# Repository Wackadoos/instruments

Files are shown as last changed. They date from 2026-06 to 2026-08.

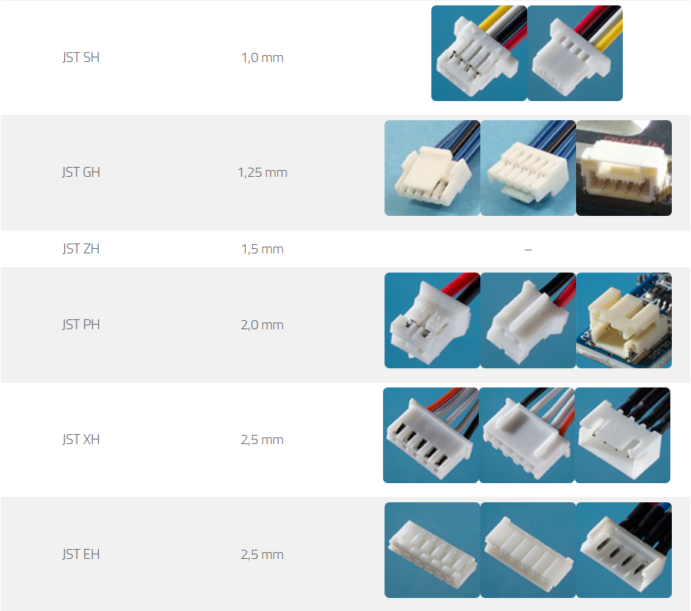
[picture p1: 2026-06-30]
circuitry/resources/JST Connector Identification.png

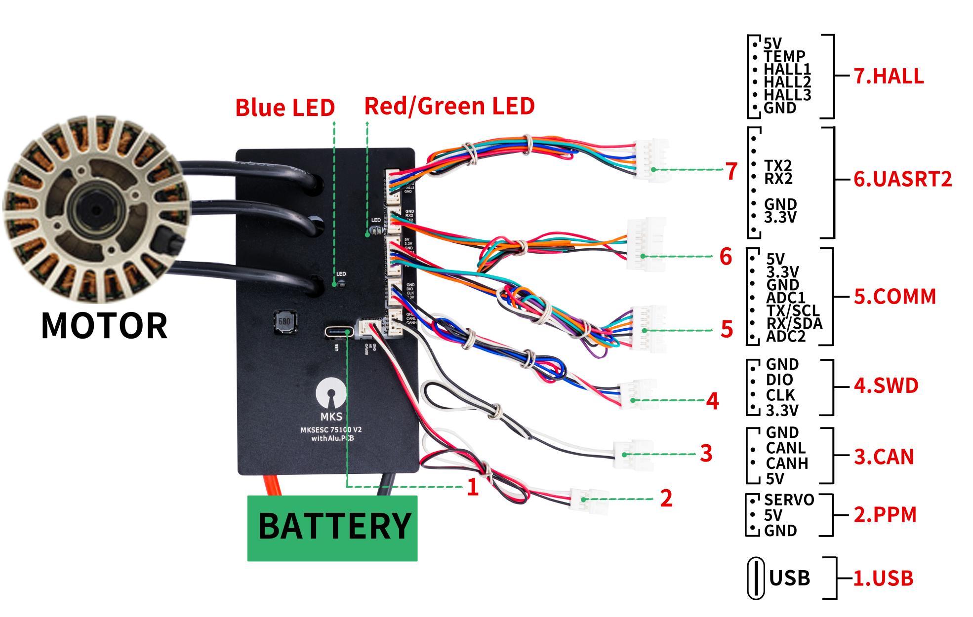
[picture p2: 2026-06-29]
circuitry/resources/Flipsky_75100.jpg

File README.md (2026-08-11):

# instruments

Software to run in-vehicle instruments

## FLIPSKY 75100 Pro v1 Settings

Unless specified below, leave settings as default!

### Firmware

Stock ESC comes with VESC v5.02. Download and flash the latest (should be v7.0 or higher). Notes:

- The hardware is classified incorrectly as 75_300_R2, this is okay as it is compatible.
- All settings will be reset with the update
- Phase Filters will be enabled by default, but are **NOT COMPATIBLE** with this hardware. If running a brushless motor (not the greenpower standard DC motor) this needs to be turned off or the hardware will be damaged!

### Motor Settings

#### General

General:

- Motor Type: DC

Current:

- Motor Current Max: 45.00 A
- Motor Current Max Brake: -45.00 A
- Absolute Maximum Current: 420.00 A
- Battery Current Max: 36.00 A
- Battery Current Max Regen: -36.00 A
- DRV8301 OC Mode: Disabled

Voltage:

- Battery Voltage Cutoff Start: 20.0 V
- Battery Voltage Cutoff End: 16.0 V
- Battery Voltage Regen Cutoff Start: 28.0 V
- Battery Voltage Regen Cutoff End: 30.0 V

Temperature:

- Motor Temperature Sensor Type: Disabled

BMS:

- BMS type: None

Advanced:

- Minimum Input Voltage: 11.0 V
- Maximum Input Voltage: 36.0 V
- Fault Stop Time: 3000 ms

#### DC

- Current Controller Gain: 0.00460
- Current Controller Ramp Step Max: 0.0400
- Current Backoff Gain: 0.5000
- Switching Frequency: 25.00 kHz

#### Additional Info

Setup:

- Battery Type: BATTERY_TYPE_LEAD_ACID
- Battery Cells Series: 12
- Battery Capacity: 36 AH
- Motor No-load Current: 1.0 A

Motor General:

- Motor Brand: Greenpower Motor
- Motor Model: 105ZDY08

### App Settings

#### General

General:

- APP to Use: ADC and UART
- Timeout Brake Current: 0.0 A
- CAN Mode: Unused
- Kill Switch Mode: PPM High

#### ADC

General:

- Control Type: Current No Reverse Brake Center
- Use Filter: True
- Safe Start: Disabled
- Update Rate: 500 Hz
- Positive Ramping Time: 0.3 s
- Negative Ramping Time: 0.1 s
- Multiple VESCs Over CAN: FALSE

Mapping:

- Input Deadband: 15%
- ADC1 Start Voltage: 0.1 V
- ADC1 End Voltage: 3.2 V
- ADC1 Centre Voltage: 1.0 V
- Invert ADC1 Voltage: False
- ADC1 Abs Min Voltage: 0.0 V
- ADC1 Abs Max Voltage: 3.5 V
- ADC2 Start Voltage: 0.1 V
- ADC2 End Voltage: 3.2 V
- Invert ADC2 Voltage: False

#### UART

Baudrate: 250000 bps

#### IMU

IMU Type: IMU_TYPE_OFF

### SWD

To program an NRF51822 for Bluetooth connectivity to the ESC, connect to the swd pins (DIO -> SDO & CLK -> SCLK) and press connect in VESC. Then, select the firmware with RX: 11 TX: 9 and flash it. After, you can connect the pins P0.11 -> TX2 and P0.9 -> RX2 to allow the bluetooth module to talk to the ESC on it's secondary serial port (leaving the primary for app usage ie connecting with arduino etc.)

## SD Cards

### Detecting Fake Cards

https://github.com/AltraMayor/f3

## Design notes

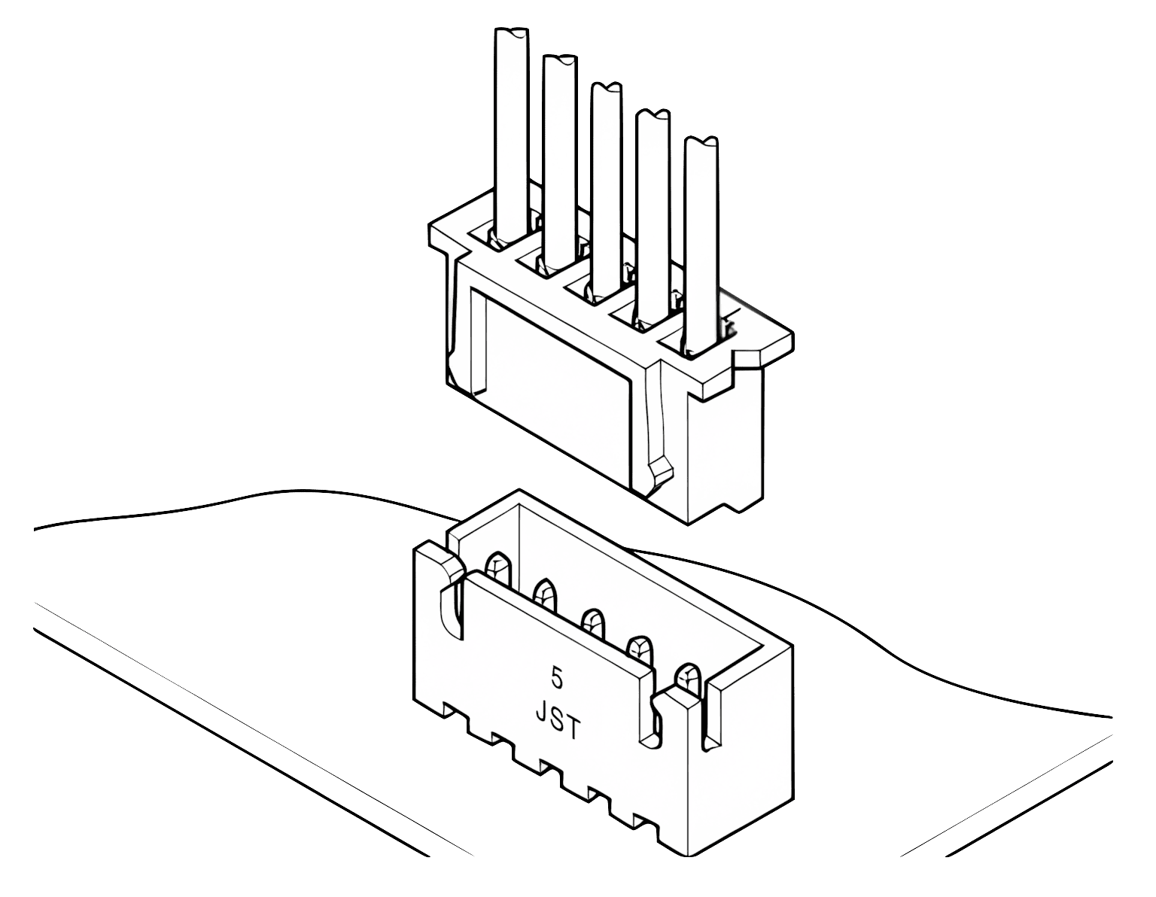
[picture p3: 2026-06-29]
circuitry/resources/JST_XH_Pinout.png

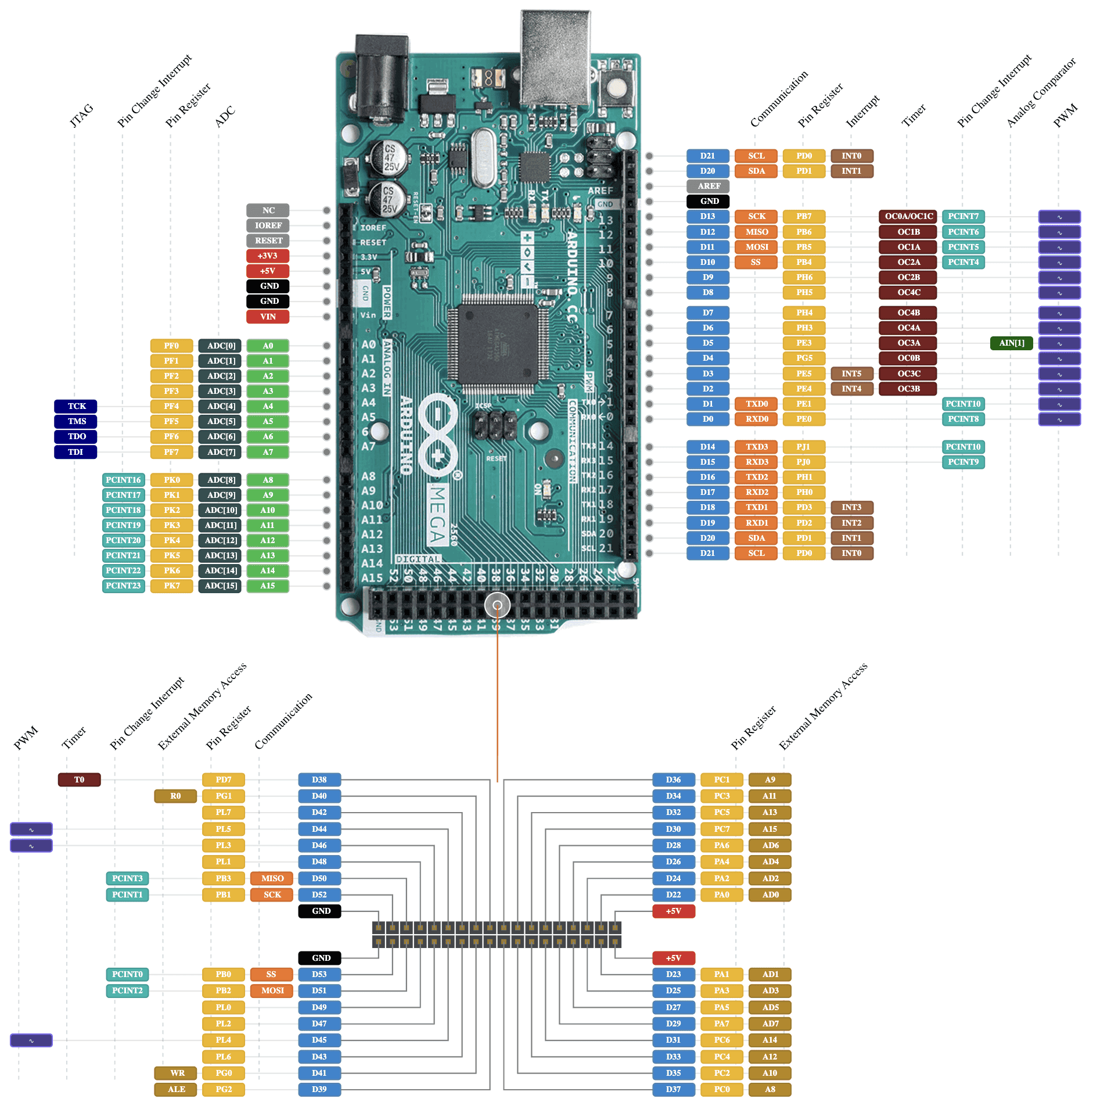
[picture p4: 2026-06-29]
circuitry/resources/Arduino_Mega.png

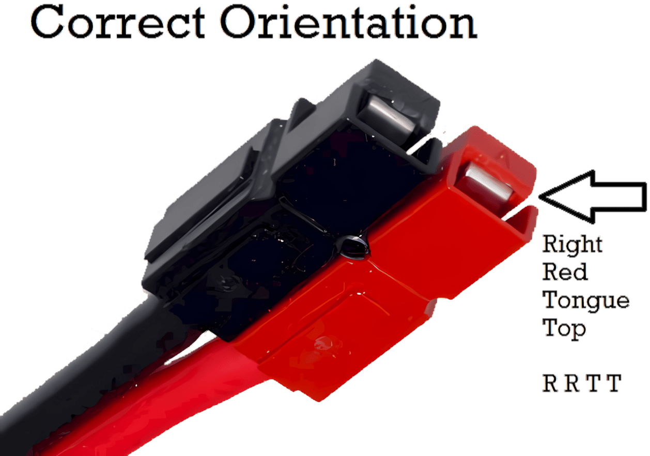
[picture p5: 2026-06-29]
circuitry/resources/PowerPole_Orientation.png

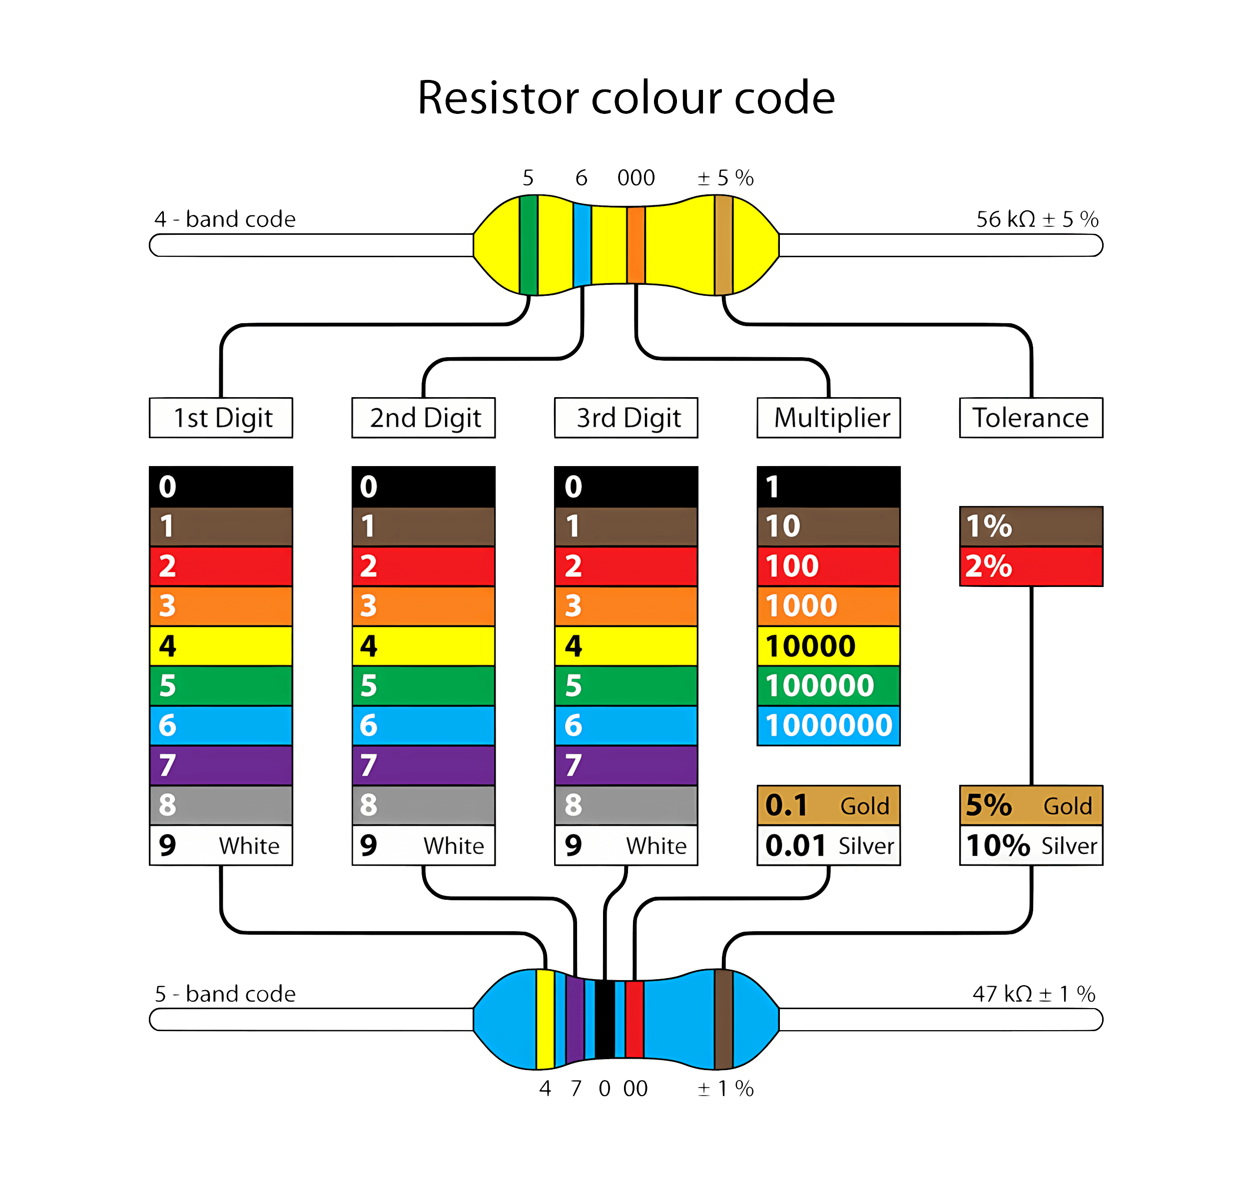
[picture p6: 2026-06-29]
circuitry/resources/Resistor_Codes.png

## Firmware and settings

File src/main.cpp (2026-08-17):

#include "main.h"

#include "hardware.h"
#include "modules/GPS.h"
#include "modules/ath20.h"
#include "modules/bmp280.h"
#include "modules/display.h"
#include "modules/imu.h"
#include "modules/rtc.h"
#include "modules/sd.h"
#include "modules/speed.h"
#include "modules/temps.h"
#include "modules/vesc.h"
#include "settings.h"
#include "state.h"
#include "utils/errors.h"
#include "utils/memory.h"
#include "utils/scheduler.h"

IntervalMetric mainLoopTime = IntervalMetric();

ScheduledTask tasks[] = {
    // ScheduledTask(500, 0, displayBattStats),
    // ScheduledTask(500, 0, displayLapTiming),
    ScheduledTask(200, 0, measureRam),
    ScheduledTask(100, 5, SPEED::update),
    ScheduledTask(250, 10, VESC::update),
    ScheduledTask(500, 100, ATH::update),
    ScheduledTask(500, 200, BMP::update),
    ScheduledTask(500, 300, TEMPS::update),
    ScheduledTask(500, 400, SD::logFrame),
    ScheduledTask(1000, 15, RTC::update),
    ScheduledTask(10000, 37, State::saveRaceState),
};

void setup() {
  Errors::init();

  HARDWARE::init();

  SETTINGS::init();

  SPEED::configure(SETTINGS::getSettings().speed_sensor_wheel_circumference, SETTINGS::getSettings().speed_sensor_pulses_per_revolution);

  State::tryResumeRace();

  mainLoopTime.init(F("Main Loop"), F("Interval measurement of main loop"));

  Scheduler::start(tasks);
}

void loop() {
  mainLoopTime.start();
  Scheduler::runTasks();
  HARDWARE::run();
  TEMPS::run();    // Runs once conversion is complete
  IMU::run();      // Internally scheduled via data ready interrupt
  GPS::run();      // Runs when new fix available
  Display::run();  // Updates displayed widgets
  SD::run();       // Drains the log ring buffer when the card is idle
  mainLoopTime.stop();
}

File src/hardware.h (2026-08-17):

#pragma once

#include <OneWire.h>

//! Arduino Mega Pin Allocation
#define GPS_PULSE_PER_SECOND_PIN 2     // INT4
#define ACCELEROMETER_INTERRUPT_PIN 3  // INT5
#define DISPLAY_BACKLIGHT_PIN 4        // High Frequency PWM
//* Hardware Serial 3 (14, 15) [Uses NeoSerial3] -> GPS Module (ATGM336H)
#define VESC_SERIAL_PORT Serial2   //* Hardware Serial 2 (16, 17) -> ESC (Flipsky 75100)
#define WHEEL_SPEED_SENSOR_PIN 18     // INT3
#define TOUCHSCREEN_INTERRUPT_PIN 19  // INT2
#define ONEWIRE_TEMPERATURE_SENSORS_PIN 42
#define DISPLAY_RESET_PIN 43
#define DISPLAY_DATA_COMMAND_PIN 47
#define SD_CARD_CHIP_SELECT_PIN 48
#define TOUCHSCREEN_CHIP_SELECT_PIN 49
//* SPI (50, 51, 52) -> Display, Touchscreen, SD Card
#define DISPLAY_CHIP_SELECT_PIN 53
#define EEPROM_I2C_ADDR 0x57
#define IMU_I2C_ADDR bfs::Mpu6500::I2C_ADDR_SEC
//* Touchscreen Calibration (resolved via Arduino_GFX TouchCalibration example)
#define TOUCH_SWAP_XY false
#define TOUCH_MAP_X1 3950
#define TOUCH_MAP_X2 150
#define TOUCH_MAP_Y1 3850
#define TOUCH_MAP_Y2 100
//* Setpoint thresholds (warning/error) for SetpointWidgets
inline float POWER_WARNING_SETPOINT = 250.0f;
inline float POWER_ERROR_SETPOINT = 500.0f;
inline float POWER_AVG_WARNING_SETPOINT = 240.0f;
inline float POWER_AVG_ERROR_SETPOINT = 340.0f;
inline float VOLTAGE_WARNING_SETPOINT = 11.5f;
inline float VOLTAGE_ERROR_SETPOINT = 10.8f;
inline float TEMP1_WARNING_SETPOINT = 35.0f;
inline float TEMP1_ERROR_SETPOINT = 45.0f;
inline float ESC_TEMP_WARNING_SETPOINT = 60.0f;
inline float ESC_TEMP_ERROR_SETPOINT = 80.0f;
inline float MOTOR_TEMP_WARNING_SETPOINT = 50.0f;
inline float MOTOR_TEMP_ERROR_SETPOINT = 65.0f;
inline uint8_t GPS_WARNING_SETPOINT = 6;
inline uint8_t GPS_ERROR_SETPOINT = 3;

class HARDWARE {
 public:
  static void init();
  static void run();

 private:
  static OneWire oneWire;
};

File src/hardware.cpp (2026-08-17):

#include "hardware.h"

#include "modules/GPS.h"
#include "modules/ath20.h"
#include "modules/bmp280.h"
#include "modules/display.h"
#include "modules/eeprom.h"
#include "modules/imu.h"
#include "modules/rtc.h"
#include "modules/sd.h"
#include "modules/speed.h"
#include "modules/temps.h"
#include "modules/vesc.h"
#include "utils/errors.h"

OneWire HARDWARE::oneWire = OneWire(ONEWIRE_TEMPERATURE_SENSORS_PIN);

void HARDWARE::init() {
  //* Set pin modes. Some of these may be set by libraries, but there's no harm in setting the same mode twice to be safe.
  pinMode(GPS_PULSE_PER_SECOND_PIN, INPUT);
  pinMode(ACCELEROMETER_INTERRUPT_PIN, INPUT);
  pinMode(DISPLAY_BACKLIGHT_PIN, OUTPUT);
  pinMode(WHEEL_SPEED_SENSOR_PIN, INPUT);  // Has external pullup
  pinMode(TOUCHSCREEN_INTERRUPT_PIN, INPUT);
  pinMode(ONEWIRE_TEMPERATURE_SENSORS_PIN, INPUT);  // Technically bidirectional, library managed onewire comms pin.
  pinMode(DISPLAY_RESET_PIN, OUTPUT);
  pinMode(DISPLAY_DATA_COMMAND_PIN, OUTPUT);
  pinMode(SD_CARD_CHIP_SELECT_PIN, OUTPUT);
  pinMode(TOUCHSCREEN_CHIP_SELECT_PIN, OUTPUT);
  pinMode(DISPLAY_CHIP_SELECT_PIN, OUTPUT);

  //* Set pin states
  digitalWrite(DISPLAY_BACKLIGHT_PIN, LOW);         //* Start with display off
  digitalWrite(DISPLAY_RESET_PIN, HIGH);            //* Display Reset pin uses LOW to reset
  digitalWrite(SD_CARD_CHIP_SELECT_PIN, HIGH);      //* SPI Chip Select uses LOW to select a device
  digitalWrite(TOUCHSCREEN_CHIP_SELECT_PIN, HIGH);  //* SPI Chip Select uses LOW to select a device
  digitalWrite(DISPLAY_CHIP_SELECT_PIN, HIGH);      //* SPI Chip Select uses LOW to select a device

#ifdef DEBUG_LOGGING
  Serial.begin(500000);
  delay(3000);
#endif

  //* SPI Devices
  Display::init(&SPI);  // Display has long blocking setup, do first
  SD::init(&SPI);       // SD shares the SPI bus via its own chip select

  //* I2C Devices
  Wire.begin();
  Wire.setWireTimeout(25000, true);  // 25ms timeout with auto reset

  EEPROM::init(&Wire);
  RTC::init(&Wire);
  BMP::init(&Wire);
  ATH::init(&Wire);
  IMU::init(&Wire);

  Wire.setClock(400000);  // Must be set after device init!

  //* OneWire Devices
  TEMPS::init(&oneWire);

  //* Serial Devices
  VESC_SERIAL_PORT.begin(250000);
  VESC::init(&VESC_SERIAL_PORT);
  GPS::init();

  //* Interrupt Devices
  SPEED::init();
}

void HARDWARE::run() {
  if (Wire.getWireTimeoutFlag()) {
    Errors::logError(Error::I2C_TIMEOUT);
    Wire.clearWireTimeoutFlag();
  }
}

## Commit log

2026-06-26 feat: Setup repo & copy demo programs
    [instruments.kicad_pcb, instruments.kicad_sch, untitled.kicad_sch]
2026-06-26 chore: Organise & formate
    [instruments.kicad_sch]
2026-06-26 feat: Add VESC config settings in README
    [instruments.kicad_sch]
2026-06-27 feat: Add connectors to circuit diagram
    [connectors.kicad_sch, instruments.kicad_sch]
2026-06-29 feat: Major circuit revision & refactor
    [auxiliary.kicad_sch, circuit.kicad_sch, connectors.kicad_sch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]
2026-06-30 feat: Add connector identification image
2026-07-05 feat: Add sensors & structure main program
    [auxiliary.kicad_sch]
2026-07-06 feat: Add Speed Module, Set Pin Modes
2026-07-08 fix: Change to 10AWG wire
    [auxiliary.kicad_sch, circuit.kicad_sch, drive.kicad_sch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]
2026-07-13 feat: Add VESC module & demo
2026-08-07 fix: Resolve circuit signal issues
    [auxiliary.kicad_sch, circuit.kicad_sch, drive.kicad_sch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]
2026-08-11 fix: Revise circuit plugs & resistors
    [auxiliary.kicad_sch, circuit.kicad_sch, drive.kicad_sch]
2026-08-11 fix: Update VESC settings
2026-08-12 feat: Add display class & Switch State to static
2026-08-13 fix: Direct string for static widgets
    [display.h]
2026-08-13 fix: Implement multi-line buttons
    [display.cpp, display.h]
2026-08-13 fix: Improve rerendering decision logic
    [display.cpp, display.h]
2026-08-13 feat: Make buttons pressable
2026-08-13 feat: Improve rtc handling, add vesc debug
2026-08-13 fix: Match vesc baud rate
    [hardware.cpp]
2026-08-14 fix: Correct temperature probe reading frequency, increase vesc polling rate
    [hardware.cpp, main.cpp, vesc.cpp]
2026-08-14 fix: Color gps display
    [display.cpp, display.h]
2026-08-15 feat: Add battery tracking, estimation & race mode persistence
2026-08-15 fix: Reduce ram stage 1
    [display.h, widgets.cpp]
2026-08-15 fix: Reduce ram 2
    [display.cpp, display.h, settings.cpp]
2026-08-15 fix: Resolve display blocking, tidy sd demos
    [SD.cpp, display.cpp, display.h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]
2026-08-15 feat: Error occurrences keep count, improve debug page speed
    [SD.cpp, debug.cpp, display.cpp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]
2026-08-15 fix: Improve display touch accuracy & timing, init uv
    [display.cpp, display.h]
2026-08-16 fix: Add 4.7k onewire pullup
    [auxiliary.kicad_sch, circuit.kicad_sch, drive.kicad_sch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]
2026-08-17 fix: Improve SD logging reliability
    [display.h, hardware.cpp, main.cpp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]
2026-08-17 feat: Add voltage & average power widgets
